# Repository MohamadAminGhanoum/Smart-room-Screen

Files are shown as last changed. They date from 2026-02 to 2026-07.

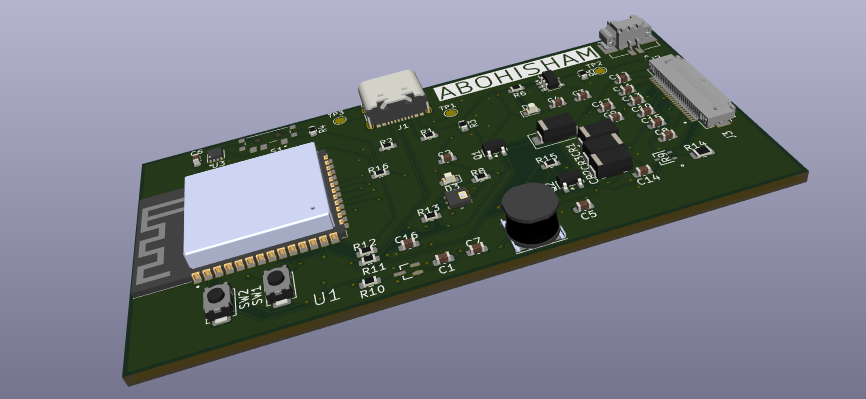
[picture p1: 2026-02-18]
assets/Screenshot 2026-02-18 at 13.41.27.png

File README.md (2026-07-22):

# Smart-room-Screen

When i usually wake up, i usually look on my phone screen to see the clock, and then i open my social media and do other stuff, which i honestly want to prevent. Therefore i have thought to make a e-ink display on the table next to me, so that i can see the clock and weather directly from my bed when i turn on my night light.

## Final look:


## DEMO
https://www.youtube.com/shorts/77qMShZQf_g



Since i made a previous project about automating my room to control, e.g led strip, open/close the curtain and also measure temperature in the room, i am thinking that i can make this hang together with my other smart-home project.  

I started by researching and mostly gained info about the style and how to connect the E-Ink display connector to the esp32. Therefore i began making schematics, and i did have to do some changes midways, because some components that i wanted were not avaliable in lcsc eleectronics. Therefore i had to search for alternatives. 

Note: the firmware right now is untested, i will do an update for the firmware when this gets approved.

How to use this:
-----------------
This is pretty simple to use, after soldering all the parts on the pcb, it is possible to see the board as a devboard, with some additional components, such as the connector for the E-ink display. The code is flashed normally into the board using the usb-c, and then it is possible to make it work over wifi if wanted, or i can also use this with only the sensor, and the time would be saved, since it is connected through a battery.

This project will allow me to see the time, and through the HTU21D, i can see the temperature and humidity in my room. 
(I will somehow try to connect this to one of my previous projects, where i made a mini smart-home, where i controlled the brightness of the LED and automated opening/ closing the Curtain. I will most likely do future updates on that projects so it becomes possible to connect them.)

## The finished schematics:



## The finished PCB looks like this:



The rendering files or CAD files with/without the screen(The screen is the same size, but not the same type as the one in aliexpress):





## BOM (scroll to the right to see the links):

|Id |Designator |Footprint |Quantity|Comment |LCSC quantity |Price |Link |
|---|---|---|---|---|---|---|---|
|1  |C1,C2,C4 |C_0603_1608Metric |3 |10uF |10 |$0.41 |https://www.lcsc.com/product-detail/C342875.html |
|2  |CR3,CR1,CR2 |CR_R1_00001_PNJ |3 |SS2040FL_R1_00001 |10 |$0.65 |https://www.lcsc.com/product-detail/C7320202.html |
|3  |R14 |R_0805_2012Metric |2 |0.47R |100 |$0.48 |https://www.lcsc.com/product-detail/C2930220.html |
|4  |R8,R7 |R_0603_1608Metric |2 |4.7K |100 |$0.13 |https://www.lcsc.com/product-detail/C99782.html |
|5  |C8,C12,C9,C10,C15,C13,C11|C_0603_1608Metric |7 |4.7uF, 25V |10 |$0.16 |https://www.lcsc.com/product-detail/C69335.html |
|6  |C6,C7,C5,C16 |C_0603_1608Metric |4 |100nF |100 |$0.35 |https://www.lcsc.com/product-detail/C1590.html |
|7  |J1 |USB_C_Receptacle_XKB_U262-16XN-4BVC11|2 |USB_C_Receptacle_USB2.0_14P |5 |$0.89 |https://www.lcsc.com/product-detail/C165948.html |
|8  |SW2 |SW_SPST_TS-1088-xR020 |2 |reset/boot |10 |$0.45 |https://www.lcsc.com/product-detail/C2846765.html |
|9  |R11,R12 |R_0603_1608Metric |2 |33R |100 |$0.10 |https://www.lcsc.com/product-detail/C2909394.html |
|10 |U6 |XCVR_ESP32-S3-WROOM-1-N4 |2 |ESP32-S3-WROOM-1-N4 |2 |$8.85 |https://www.lcsc.com/product-detail/C2913197.html |
|11 |R5 |R_0603_1608Metric |1 |3K |100 |$0.10 |https://www.lcsc.com/product-detail/C2907033.html |
|12 |U5 |QFN100P300X300X100-7N |1 |HTU21D |2 |$4.29 |https://www.lcsc.com/product-detail/C83479.html |
|13 |J2 |532610271:MOLEX_532610271 |1 |battery connector |5 |$0.85 |https://www.lcsc.com/product-detail/C177225.html |
|14 |R10,R13,R4 |R_0603_1608Metric |2 |10K |100 |$0.11 |https://www.lcsc.com/product-detail/C25804.html |
|15 |S1 |SW_SLW-66527511-SMT-TR |1 |SLW-66527511-SMT-TR |5 |$0.39 |https://www.lcsc.com/product-detail/C49023765.html |
|16 |D3,D2 |LED_0603_1608Metric |2 |LED |100 |$0.58 |https://www.lcsc.com/product-detail/C19171392.html |
|18 |R2,R1 |R_0603_1608Metric |2 |5.1K |100 |$0.12 |https://www.lcsc.com/product-detail/C23186.html |
|19 |U4 |SOT-23-5 |1 |MCP73831-3-OT |3 |$2.18 |https://www.lcsc.com/product-detail/C424093.html |
|20 |J3 |AMPHENOL_F34G-1A7Q1-E8C24 |1 |F34G-1A7Q1-E8C24 |5 |$0.25 |https://www.lcsc.com/product-detail/C53223239.html |
|21 |R16 |R_0603_1608Metric |1 |1K |100 |$0.13 |https://www.lcsc.com/product-detail/C22548.html |
|22 |D1 |D_SMA |1 |SS14 |5 |$0.61 |https://www.lcsc.com/product-detail/C83852.html |
|23 |R6 |R_0603_1608Metric |1 |470 |100 |$0.12 |https://www.lcsc.com/product-detail/C23179.html |
|24 |C14,C17 |C_0603_1608Metric |2 |4.7uF,25V |50 |$0.44 |https://www.lcsc.com/product-detail/C6119856.html |
|25 |R3 |R_0603_1608Metric |1 |100K |100 |$0.13 |https://www.lcsc.com/product-detail/C14675.html |
|26 |L1 |L_Taiyo-Yuden_MD-4040 |1 |10uH |5 |$0.89 |https://www.lcsc.com/product-detail/C92966.html |
|28 |R15 |R_0603_1608Metric |1 |47K |100 |$0.14 |https://www.lcsc.com/product-detail/C105579.html |
|29 |U3 |SON50P200X200X60-9N |1 |ADP124ACPZ-3.3-R7 |3 |$4.27 |https://www.lcsc.com/product-detail/C658731.html |
|30 |R9 |SOT-323T_ROM |1 |RTF025N03TL |5 |$1.56 |https://www.lcsc.com/product-detail/C3281999.html |
|31 |C3 |C_0603_1608Metric |1 |4.7uF |50 |$0.28 |https://www.lcsc.com/product-detail/C1705.html |
|32 |Q2,Q1 |SOT-23 |2 |AO3401A |20 |$0.71 |https://www.lcsc.com/product-detail/C5296722.html |
|33 |U1 |SOT65P210X110-3N |1 |ADM803SAKSZ-REEL |5 |$0.93 |https://www.lcsc.com/product-detail/C52146012.html |
|34 |E-ink display |N/A |1 |HINK-E042A31-A1 4.2inch E-Ink | |$16.00|https://www.aliexpress.com/item/1005006894281685.html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 |
|35 |803040 LiPo |N/A |1 |803040 LiPo battery with protection| |$9.35 |https://www.aliexpress.com/item/32583451110.html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 |
|36 |PCB |N/A |5 |JLCPCB | |$4.00 | |
|37 |Threaded inserts |N/A |4 |Aliexpress | |$2.19 |https://www.aliexpress.com/item/1005007640664497.html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|
| | | | | | | | |
| | | | | |Total with shipping, 3d printing legion:|$82.01| |

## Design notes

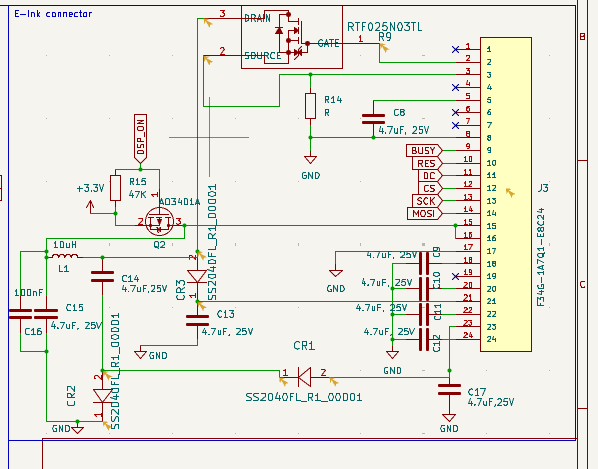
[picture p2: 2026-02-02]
assets/Screenshot 2026-01-24 at 19.53.34.png

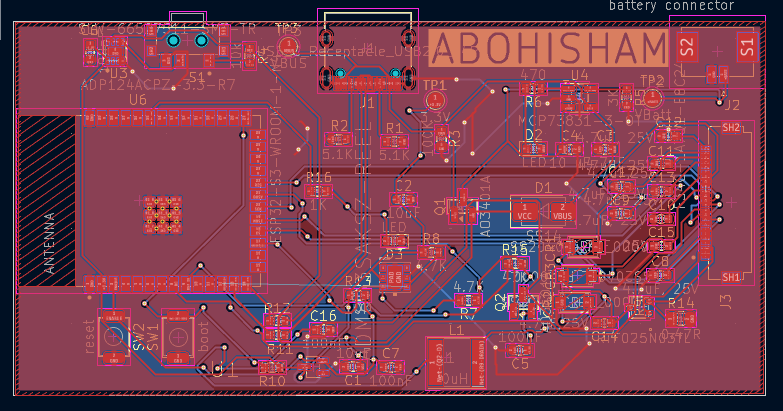
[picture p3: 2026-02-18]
assets/Screenshot 2026-02-18 at 15.17.08.png

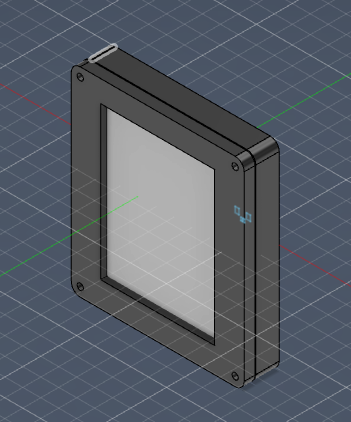
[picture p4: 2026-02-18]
assets/Screenshot 2026-02-18 at 15.44.37.png

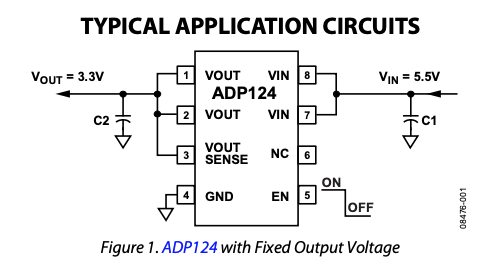
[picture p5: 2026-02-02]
assets/Screenshot 2026-01-24 at 14.05.35.png

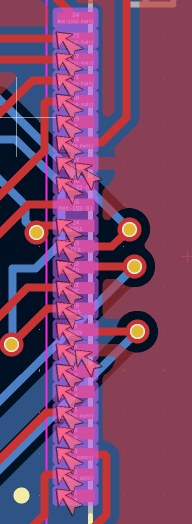
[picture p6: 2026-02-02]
assets/Screenshot 2026-01-25 at 16.29.16.png

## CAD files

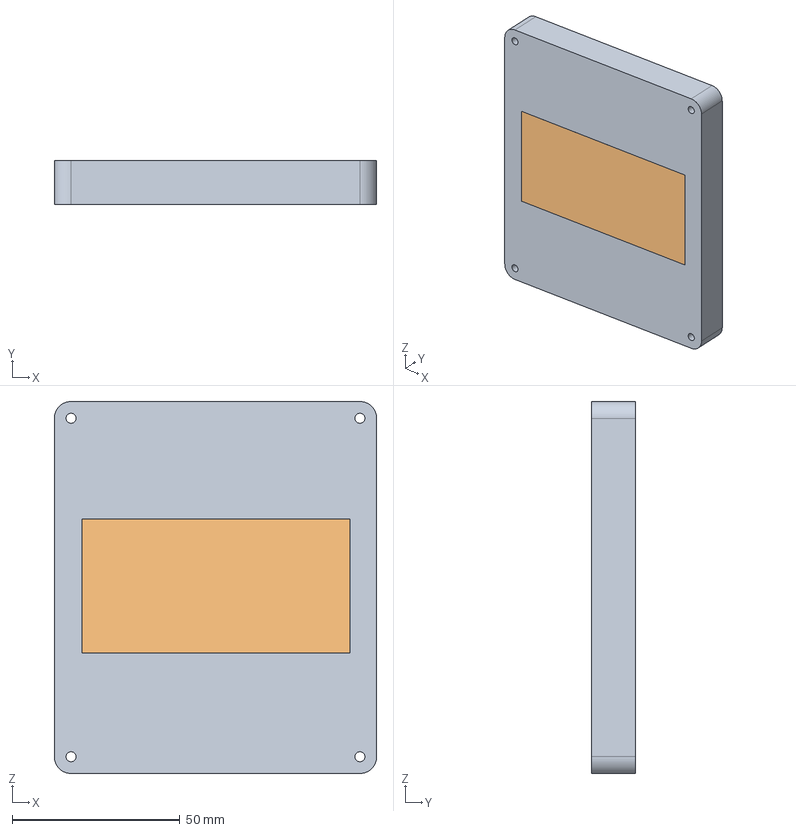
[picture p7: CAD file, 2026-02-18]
Step-files (PCB & CAD)/Back-display-o.step
96.2 x 13.0 x 111.0 mm

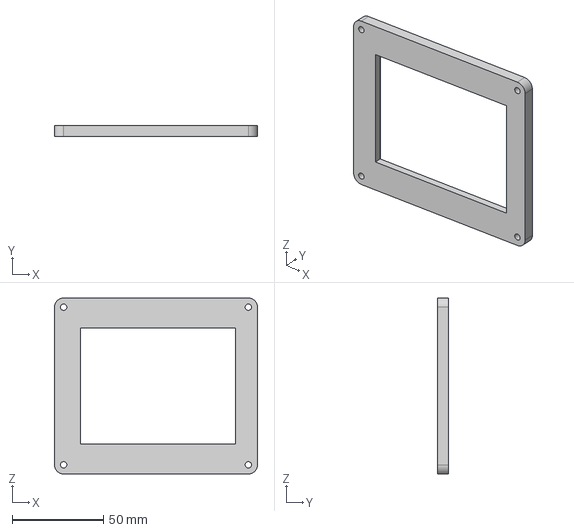
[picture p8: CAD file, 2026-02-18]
Step-files (PCB & CAD)/Front-Display-o.step
111.0 x 6.00 x 96.2 mm

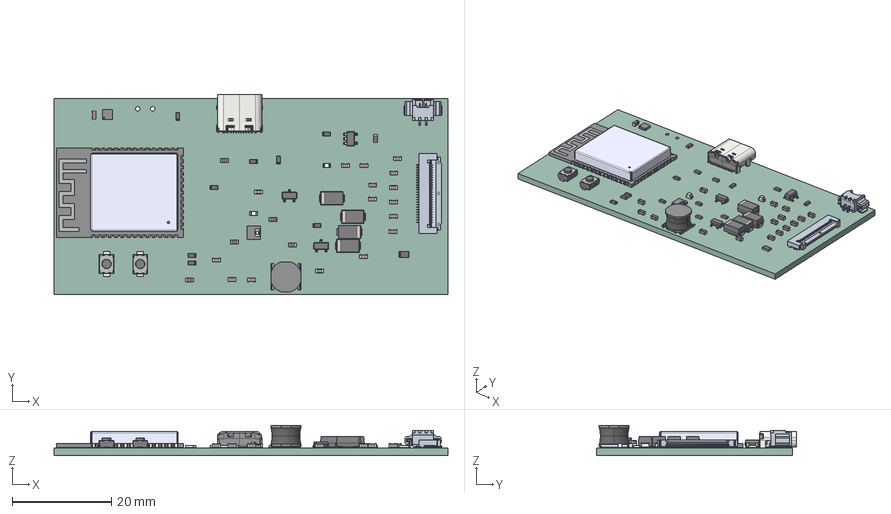
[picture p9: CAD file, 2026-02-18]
Step-files (PCB & CAD)/Smart-room Screen pcb.step
79.2 x 40.2 x 6.09 mm
C_0603_1608Metric x 17
D_SMA x 4
R_0805_2012Metric
R_0603_1608Metric x 14
USB_C_Receptacle_GCT_USB4105-xx-A_16P_TopMnt_Horizontal
SW_SPST_TS-1088-xR020 x 2
ESP32-S3-WROOM-1-N4
HTU21D
LED_0603_1608Metric x 2
SOT-23-5
F34G-1A7Q1-E8C24
1255AY-100M=P3
ADP124ACPZ-3.3-R7
SOT-23 x 2
Smart-room Screen_PCB

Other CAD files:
F3d or F3z CAD files/Back-display-o.f3d
F3d or F3z CAD files/Front-Display-0.f3d
F3d or F3z CAD files/Whole assembled.f3z

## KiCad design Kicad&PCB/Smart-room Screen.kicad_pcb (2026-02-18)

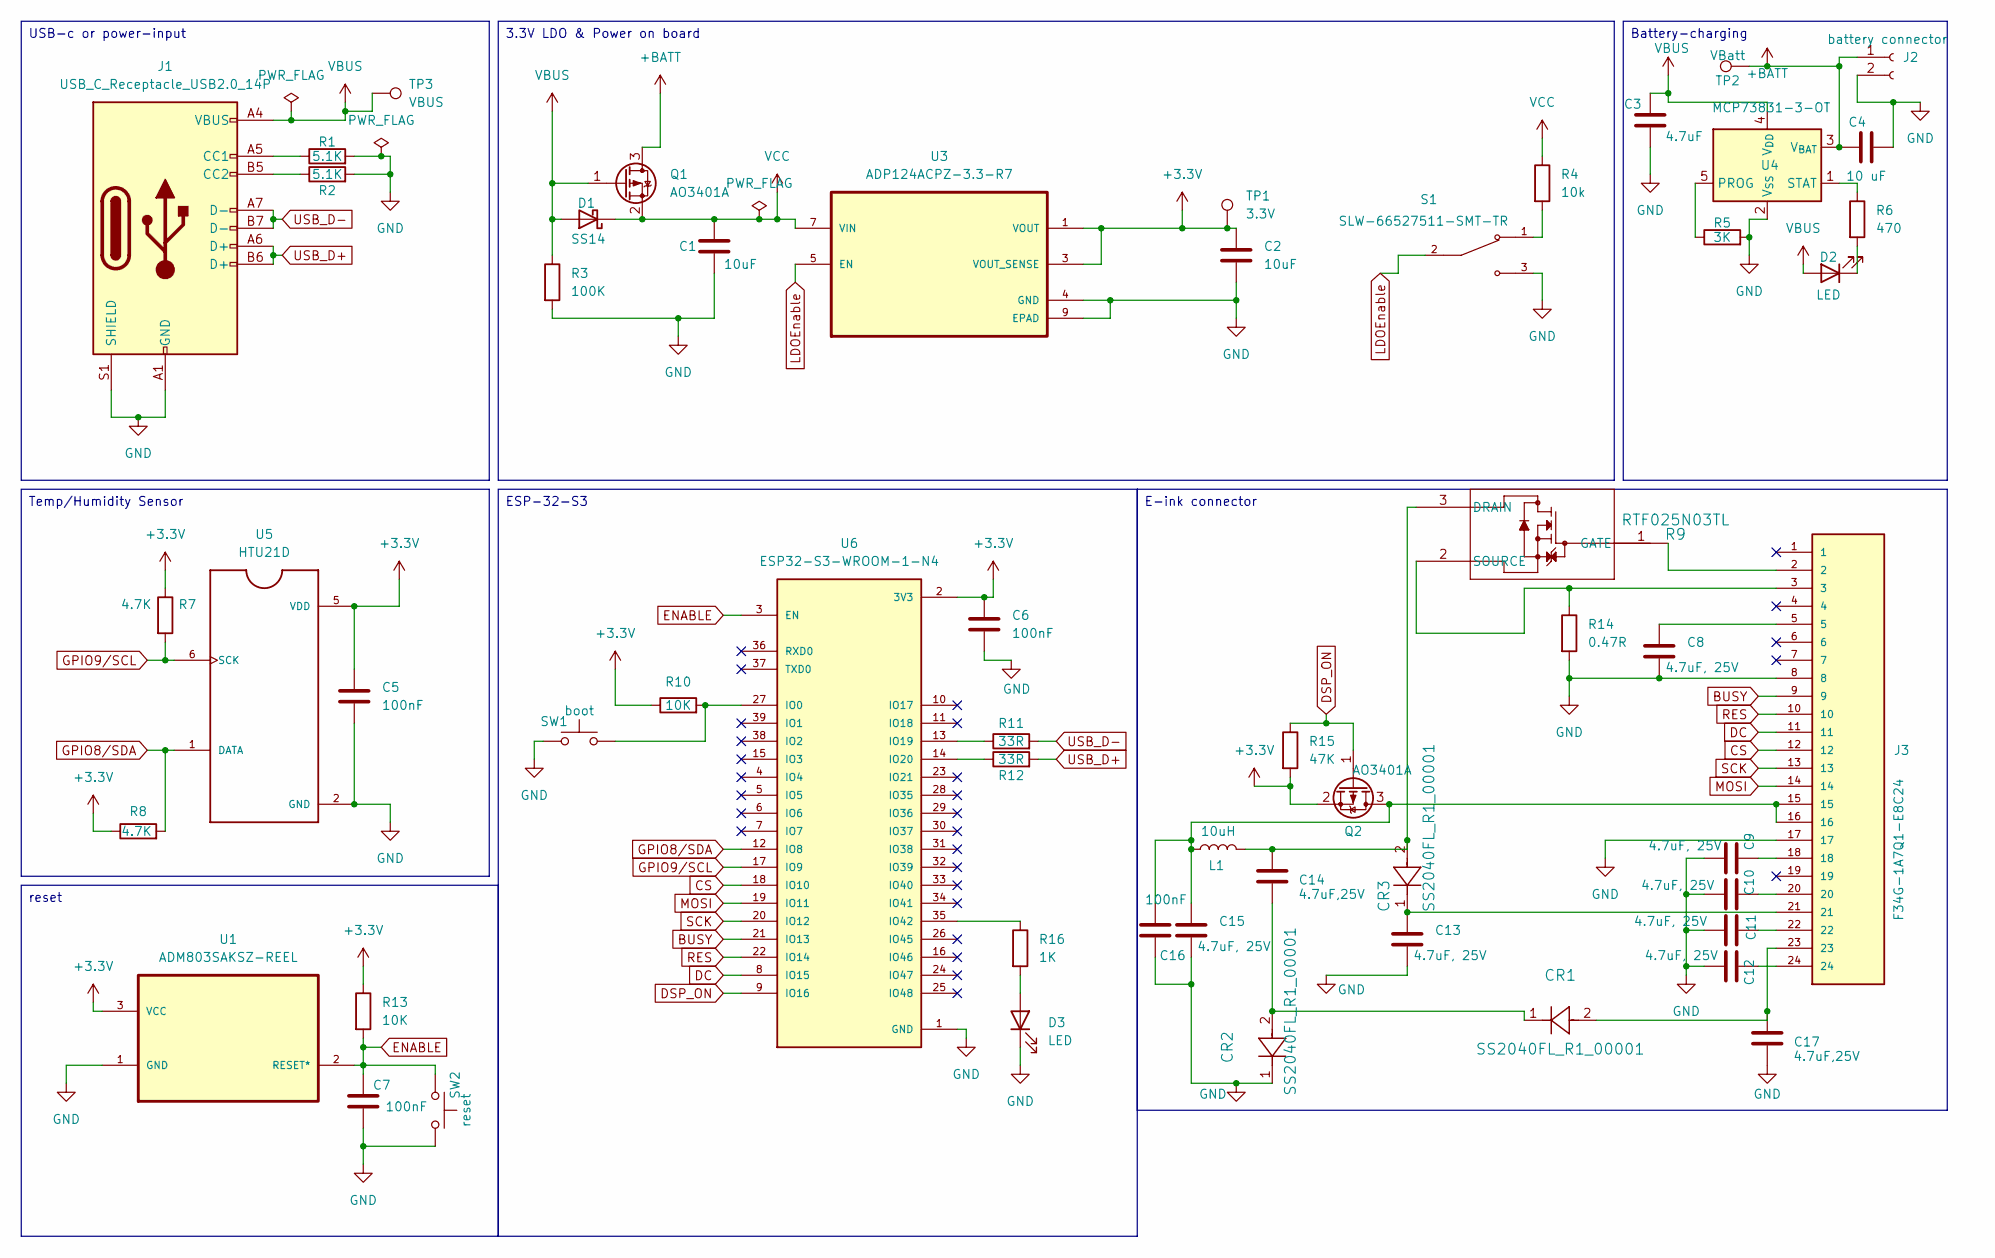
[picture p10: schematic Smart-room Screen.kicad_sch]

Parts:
C1, C2: 10uF; C_0603_1608Metric
C3: 4.7uF; C_0603_1608Metric
C4: 10 uF; C_0603_1608Metric
C5, C6, C7, C16: 100nF; C_0603_1608Metric
C8, C9, C10, C11, C12, C13, C15: 4.7uF, 25V; C_0603_1608Metric
C14, C17: 4.7uF,25V; C_0603_1608Metric
CR1, CR2, CR3: SS2040FL_R1_00001; CR_R1_00001_PNJ
D1: SS14; D_SMA
D2, D3: LED; LED_0603_1608Metric
J1: USB_C_Receptacle_USB2.0_14P; USB_C_Receptacle_XKB_U262-16XN-4BVC11
J2: battery connector; JST_PH_S2B-PH-SM4-TB_1x02-1MP_P2.00mm_Horizontal
J3: F34G-1A7Q1-E8C24; AMPHENOL_F34G-1A7Q1-E8C24; PARTREV A
L1: 10uH; L_Taiyo-Yuden_MD-4040
Q1, Q2: AO3401A; SOT-23
R1, R2: 5.1K; R_0603_1608Metric
R3: 100K; R_0603_1608Metric
R4: 10k; R_0603_1608Metric
R5: 3K; R_0603_1608Metric
R6: 470; R_0603_1608Metric
R7, R8: 4.7K; R_0603_1608Metric
R9: RTF025N03TL; SOT-323T_ROM
R10, R13: 10K; R_0603_1608Metric
R11, R12: 33R; R_0603_1608Metric
R14: 0.47R; R_0805_2012Metric
R15: 47K; R_0603_1608Metric
R16: 1K; R_0603_1608Metric
S1: SLW-66527511-SMT-TR; SW_SLW-66527511-SMT-TR; PARTREV 1.01
SW1: boot; SW_SPST_TS-1088-xR020
SW2: reset; SW_SPST_TS-1088-xR020
TP1: 3.3V; TestPoint_Pad_D1.5mm
TP2: VBatt; TestPoint_Pad_D1.5mm
TP3: VBUS; TestPoint_Pad_D1.5mm
U1: ADM803SAKSZ-REEL; SOT65P210X110-3N; MPN ADM803SAKSZ-REEL
U3: ADP124ACPZ-3.3-R7; SON50P200X200X60-9N; PARTREV D
U4: MCP73831-3-OT; SOT-23-5
U5: HTU21D; QFN100P300X300X100-7N
U6: ESP32-S3-WROOM-1-N4; XCVR_ESP32-S3-WROOM-1-N4; PARTREV v1.0

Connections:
+3.3V: C2.1, C5.1, C6.1, Q2.2 (S), R7.1, R8.1, R10.1, R13.1, R15.2, TP1.1, U1.3 (VCC), U3.1 (VOUT), U3.2 (VOUT), U3.3 (VOUT_SENSE), U5.5 (VDD), U6.2 (3V3)
+BATT: C4.1, J2.1, Q1.3 (D), TP2.1, U4.3 (V_{BAT})
BUSY: J3.9, U6.21 (IO13)
CS: J3.12, U6.18 (IO10)
DC: J3.11, U6.8 (IO15)
DSP_ON: Q2.1 (G), R15.1, U6.9 (IO16)
ENABLE: C7.1, R13.2, SW2.1, U1.2 (RESET*), U6.3 (EN)
GND: C1.2, C2.2, C3.1, C4.2, C5.2, C6.2, C7.2, C8.1, C9.2, C10.2, C11.2, C12.2, C13.1, C15.1, C16.2, C17.2, CR2.1, D3.1 (K), J1.A1 (GND), J1.A12 (GND), J1.B1 (GND), J1.B12 (GND), J1.S1 (SHIELD), J2.2, J3.8, J3.17, R1.2, R2.2, R3.2, R5.2, R14.2, S1.3, SW1.1, SW2.2, U1.1 (GND), U3.4 (GND), U3.9 (EPAD), U4.2 (V_{SS}), U5.2 (GND), U5.PAD (GND), U6.1 (GND), U6.40 (GND), U6.41_1 (GND), U6.41_2 (GND), U6.41_3 (GND), U6.41_4 (GND), U6.41_5 (GND), U6.41_6 (GND), U6.41_7 (GND), U6.41_8 (GND), U6.41_9 (GND), U6.41_10, U6.41_11, U6.41_12, U6.41_13, U6.41_14, U6.41_15, U6.41_16, U6.41_17, U6.41_18, U6.41_19, U6.41_20, U6.41_21
GPIO8/SDA: R8.2, U5.1 (DATA), U6.12 (IO8)
GPIO9/SCL: R7.2, U5.6 (SCK), U6.17 (IO9)
LDOEnable: S1.2, U3.5 (EN)
MOSI: J3.14, U6.19 (IO11)
unnamed: C8.2, J3.5
unnamed: C9.1, J3.18
unnamed: C10.1, J3.20
unnamed: C11.1, J3.22
unnamed: C12.1, J3.24
unnamed: C13.2, CR3.1, J3.21
unnamed: C14.2, CR1.1, CR2.2
unnamed: C17.1, CR1.2, J3.23
unnamed: D2.1 (K), R6.2
unnamed: D3.2 (A), R16.2
unnamed: J1.A5 (CC1), R1.1
unnamed: J1.B5 (CC2), R2.1
unnamed: C15.2, C16.1, J3.15, J3.16, L1.1, Q2.3 (D)
unnamed: R4.2, S1.1
unnamed: C14.1, CR3.2, L1.2, R9.3 (DRAIN)
unnamed: J3.2, R9.1 (GATE)
unnamed: J3.3, R9.2 (SOURCE), R14.1
unnamed: R5.1, U4.5 (PROG)
unnamed: R6.1, U4.1 (STAT)
unnamed: R10.2, SW1.2, U6.27 (IO0)
unnamed: R11.1, U6.13 (IO19)
unnamed: R12.1, U6.14 (IO20)
unnamed: R16.1, U6.35 (IO42)
RES: J3.10, U6.22 (IO14)
SCK: J3.13, U6.20 (IO12)
USB_D+: J1.A6 (D+), J1.B6 (D+), R12.2
USB_D-: J1.A7 (D-), J1.B7 (D-), R11.2
VBUS: C3.2, D1.2 (A), D2.2 (A), J1.A4 (VBUS), J1.A9 (VBUS), J1.B4 (VBUS), J1.B9 (VBUS), Q1.1 (G), R3.1, TP3.1, U4.4 (V_{DD})
VCC: C1.1, D1.1 (K), Q1.2 (S), R4.1, U3.7 (VIN), U3.8 (VIN)

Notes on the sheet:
3.3V LDO & Power on board
USB-c or power-input
ESP-32-S3
Battery-charging
Temp/Humidity Sensor
E-ink connector
reset

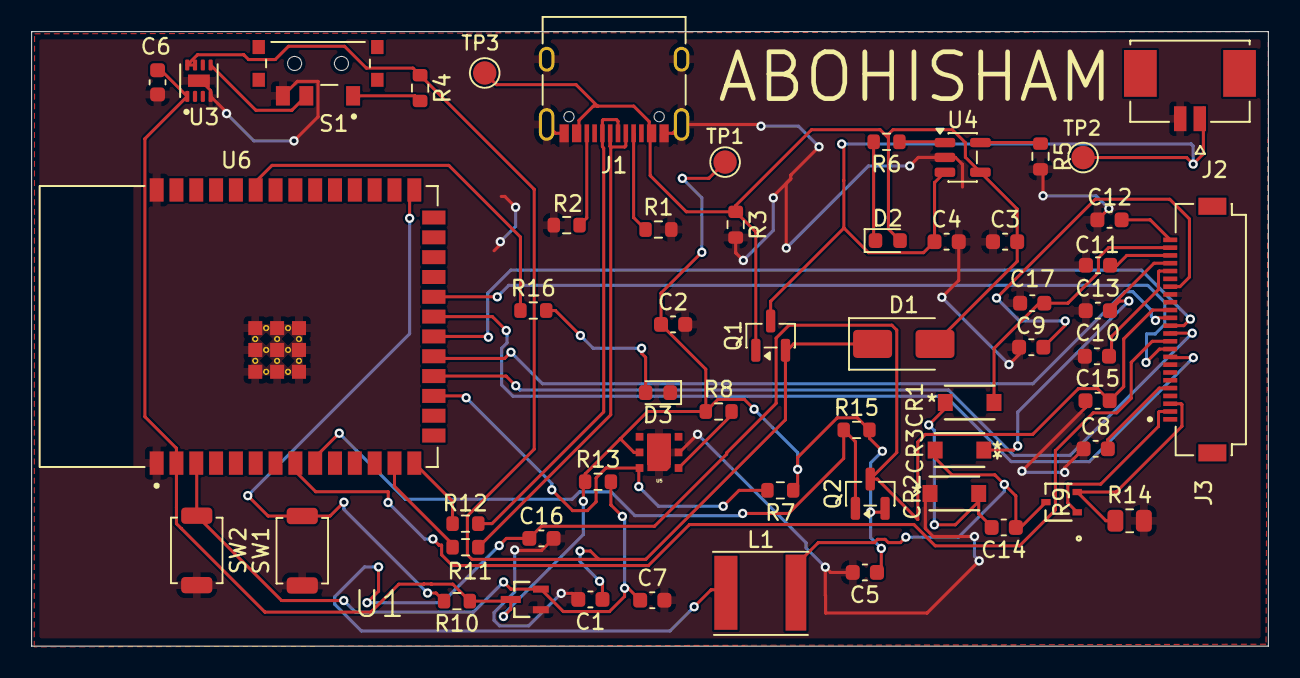
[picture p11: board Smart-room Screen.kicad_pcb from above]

Board: 2 copper layers, 79.2 x 39.4 mm, 56 parts (0 on the bottom side), 41 nets.

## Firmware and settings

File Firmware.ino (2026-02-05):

#include <WiFi.h>
#include <HTTPClient.h>
#include <time.h>

#include <GxEPD2_BW.h>
#include <Adafruit_GFX.h>

#include <DHT.h>
#include <ArduinoJson.h>

/* ================= WIFI ================= */

const char* ssid = "YOUR_WIFI_NAME";
const char* password = "YOUR_WIFI_PASSWORD";

/* ================= TIME ================= */

const char* ntpServer = "pool.ntp.org";
const long gmtOffset_sec = 0;       // Change for your country
const int daylightOffset_sec = 0;

/* ================= SENSOR ================= */

#define DHTPIN 15
#define DHTTYPE DHT22

DHT dht(DHTPIN, DHTTYPE);

/* ================= E-INK DISPLAY ================= */

// Change model if needed
GxEPD2_BW<GxEPD2_213_B73, GxEPD2_213_B73::HEIGHT> display(
  GxEPD2_213_B73(5, 17, 16, 4) // CS, DC, RST, BUSY
);

/* ================= API ================= */

String apiURL = "https://api.coindesk.com/v1/bpi/currentprice.json";

/* ================= FUNCTIONS ================= */

void connectWiFi()
{
  WiFi.begin(ssid, password);

  Serial.print("Connecting");
  while (WiFi.status() != WL_CONNECTED)
  {
    delay(500);
    Serial.print(".");
  }

  Serial.println("\nWiFi Connected!");
}

String getTime()
{
  struct tm timeinfo;

  if (!getLocalTime(&timeinfo))
  {
    return "No Time";
  }

  char buffer[30];
  strftime(buffer, 30, "%H:%M:%S", &timeinfo);

  return String(buffer);
}

float getOnlineData()
{
  HTTPClient http;
  http.begin(apiURL);

  int code = http.GET();

  if (code == 200)
  {
    String payload = http.getString();

    DynamicJsonDocument doc(2048);
    deserializeJson(doc, payload);

    float price = doc["bpi"]["USD"]["rate_float"];

    http.end();
    return price;
  }

  http.end();
  return -1;
}

void drawScreen(String timeStr, float temp, float hum, float online)
{
  display.setFullWindow();
  display.firstPage();

  do
  {
    display.fillScreen(GxEPD_WHITE);

    display.setTextColor(GxEPD_BLACK);

    display.setTextSize(2);
    display.setCursor(10, 25);
    display.println("ESP32 E-Ink");

    display.setTextSize(2);
    display.setCursor(10, 55);
    display.print("Time: ");
    display.println(timeStr);

    display.setCursor(10, 85);
    display.print("Temp: ");
    display.print(temp);
    display.println(" C");

    display.setCursor(10, 110);
    display.print("Hum: ");
    display.print(hum);
    display.println(" %");

    display.setCursor(10, 140);
    display.print("BTC: $");

    if (online > 0)
      display.println(online);
    else
      display.println("Error");

  }
  while (display.nextPage());
}

/* ================= SETUP ================= */

void setup()
{
  Serial.begin(115200);

  display.init();

  dht.begin();

  connectWiFi();

  configTime(gmtOffset_sec, daylightOffset_sec, ntpServer);
}

/* ================= LOOP ================= */

void loop()
{
  String timeNow = getTime();

  float temperature = dht.readTemperature();
  float humidity = dht.readHumidity();

  float onlineValue = getOnlineData();

  Serial.println("Updating display...");

  drawScreen(timeNow, temperature, humidity, onlineValue);

  // Sleep 5 minutes (e-ink friendly)
  delay(300000);
}

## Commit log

2026-01-25 Rename Smart-room Screen.kicad_dru to Kicad&PCB/Smart-room Screen.kicad_dru
2026-01-25 Rename Smart-room Screen.kicad_pcb to Kicad&PCB/Smart-room Screen.kicad_pcb
    [Smart-room Screen.kicad_pcb]
2026-01-25 Rename Smart-room Screen.kicad_prl to Kicad&PCB/Smart-room Screen.kicad_prl
2026-01-25 Rename Smart-room Screen.kicad_pro to Kicad&PCB/Smart-room Screen.kicad_pro
2026-01-25 Rename Smart-room Screen.kicad_sch to Kicad&PCB/Smart-room Screen.kicad_sch
    [Smart-room Screen.kicad_sch]
2026-02-02 Rename Smart-room Screen.step to Smart-room Screen.step
    [Smart-room Screen.step]
2026-02-02 Update README with project details and schematics
    Added details about the project and schematics.
2026-02-02 Update README with finished schematics and PCB images
    Added images of the finished schematics and PCB.
2026-02-02 Update README with BOM and project details
    Added a Bill of Materials (BOM) section with details for components used in the project.
2026-02-02 Fix BOM link and improve README formatting
    Updated the BOM link and corrected formatting issues.
2026-02-02 Revise BOM format and add new components
    Updated BOM table format and added new entries.
2026-02-02 Fix formatting and add BOM section to README
    Updated the README to improve formatting and clarity.
2026-02-05 Update and rename Smart-room Screen.step to Smart-room Screen PCB.step
    [Smart-room Screen PCB.step]
2026-02-05 Update README with rendering and CAD files information
    Added rendering and CAD files section with images.
2026-02-05 Add initial firmware for ESP32 with e-ink display
2026-02-05 Rename Assembled with pcb.f3z to F3d or F3z CAD files/Assembled with pcb.f3z
    [Assembled with pcb.f3z]
2026-02-05 Revise BOM with new components and pricing
    Updated component list and prices in BOM for Room-smart-screen.
    [BOM - Room-smart-screen.csv]
2026-02-18 Add new image to README and update PCB screenshot
2026-02-19 Update README with rendering and CAD file images
    Added images of rendering files and CAD files.
2026-06-25 Clean up README.md by removing BOM cart pictures
    Removed unnecessary BOM cart pictures and cleaned up the formatting.
